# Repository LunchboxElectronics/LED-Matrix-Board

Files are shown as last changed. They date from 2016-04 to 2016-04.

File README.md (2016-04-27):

# README #

Whoray a LEGO compatible LED Matrix Board!!

### What is this repository for? ###

This repo supplies instructions and source files to create and make derivatives of the LED Matrix Board kit. This kit is an array of 49 LEDs to be incorperated into existing brick projects. The board is compatible with LEGO sets.

* This repo contains:
Eagle Files 
Arduino code to run the display and animate a smile

### How do I get set up? ###

* Code is written in Arduino
* Board file and schematic are created in Eagle

### Licensing ###
LED Matrix Board is an open source hardware product and follows the open source hardware definition: www.oshwa.org/definition The Eagle Files are licensed CC-BY-SA: Lunchbox Electronics.

### Warrenty ###
Distributed as-is; no warranty given. Not suitable for people who might eat electronics.

### Who do I talk to? ###

* Created by Jason Brownstein @ Lunchbox Electronics 9/24/15
* Contact contact@lunchboxelectronics.com

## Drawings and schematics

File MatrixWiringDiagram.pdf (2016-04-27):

# LED Matrix Board Hook-Up

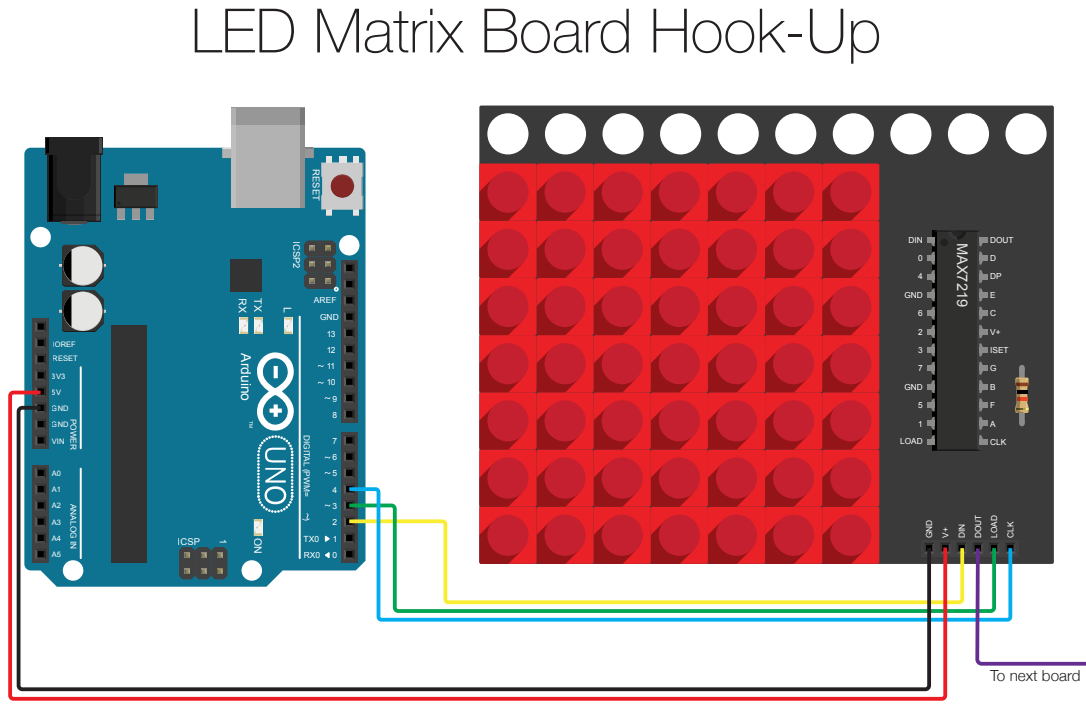
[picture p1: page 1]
ANALOG IN; AREF; GND; RESET; VIN; DIGITAL (PWM= ); Arduino TM; IOREF; ICSP; ICSP2; POWER; RX0RESET; DIN; MAX7219; DOUT; ISET; CLK; LOAD

To next board

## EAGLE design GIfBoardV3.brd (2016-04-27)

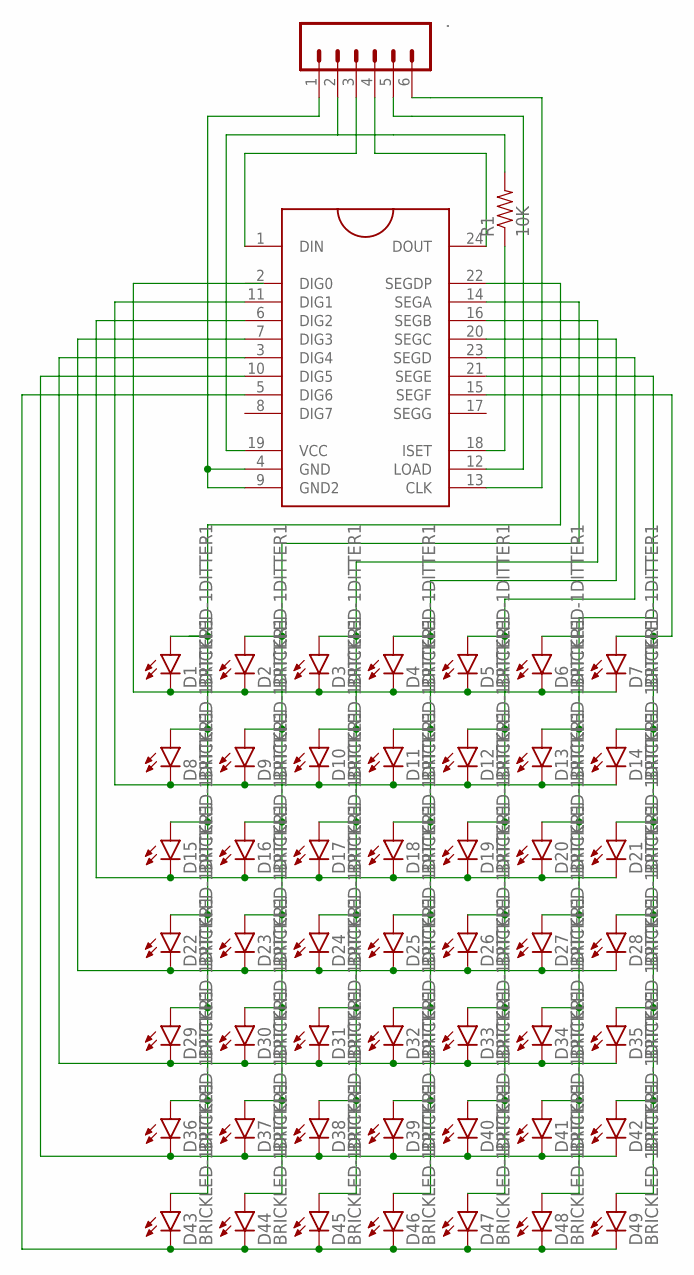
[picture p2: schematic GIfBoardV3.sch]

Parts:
.: M06NO_SILK_FEMALE_PTH; 1X06_NO_SILK
D1, D2, D3, D4, D5, D6, D7, D8, D9, D10, D11, D12, D13, D14, D15, D16, D17, D18, D19, D20, D21, D22, D23, D24, D25, D26, D27, D28, D29, D30, D31, D32, D33, D34, D35, D36, D37, D38, D39, D40, D41, D42, D43, D44, D45, D46, D47, D48, D49: BRICKLED-1DITTER1; BRICKLED-1DITTER
MAX7219: MAX7219DIP; DIL24
R1: 10K; AXIAL-0.3

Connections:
unnamed: ..4, MAX7219.24 (DOUT)
unnamed: ..5, MAX7219.12 (LOAD)
unnamed: ..3, MAX7219.1 (DIN)
unnamed: ..1, MAX7219.4 (GND), MAX7219.9 (GND2)
unnamed: D8.K (C), D9.K (C), D10.K (C), D11.K (C), D12.K (C), D13.K (C), D14.K (C), MAX7219.11 (DIG1)
unnamed: ..2, MAX7219.19 (VCC), R1.P$2 (2)
unnamed: ..6, MAX7219.13 (CLK)
unnamed: D1.A, D8.A, D15.A, D22.A, D29.A, D36.A, D43.A, MAX7219.22 (SEGDP)
unnamed: D1.K (C), D2.K (C), D3.K (C), D4.K (C), D5.K (C), D6.K (C), D7.K (C)
unnamed: D15.K (C), D16.K (C), D17.K (C), D18.K (C), D19.K (C), D20.K (C), D21.K (C), MAX7219.6 (DIG2)
unnamed: D2.A, D9.A, D16.A, D23.A, D30.A, D37.A, D44.A, MAX7219.14 (SEGA)
unnamed: D29.K (C), D30.K (C), D31.K (C), D32.K (C), D33.K (C), D34.K (C), D35.K (C), MAX7219.3 (DIG4)
unnamed: D36.K (C), D37.K (C), D38.K (C), D39.K (C), D40.K (C), D41.K (C), D42.K (C), MAX7219.10 (DIG5)
unnamed: D43.K (C), D44.K (C), D45.K (C), D46.K (C), D47.K (C), D48.K (C), D49.K (C), MAX7219.5 (DIG6)
unnamed: MAX7219.18 (ISET), R1.P$1 (1)
unnamed: D3.A, D10.A, D17.A, D24.A, D31.A, D38.A, D45.A, MAX7219.16 (SEGB)
unnamed: D5.A, D12.A, D19.A, D26.A, D33.A, D40.A, D47.A, MAX7219.23 (SEGD)
unnamed: D4.A, D11.A, D18.A, D25.A, D32.A, D39.A, D46.A, MAX7219.20 (SEGC)
unnamed: D6.A, D13.A, D20.A, D27.A, D34.A, D41.A, D48.A, MAX7219.21 (SEGE)
unnamed: D7.A, D14.A, D21.A, D28.A, D35.A, D42.A, D49.A, MAX7219.15 (SEGF)
unnamed: D22.K (C), D23.K (C), D24.K (C), D25.K (C), D26.K (C), D27.K (C), D28.K (C), MAX7219.7 (DIG3)

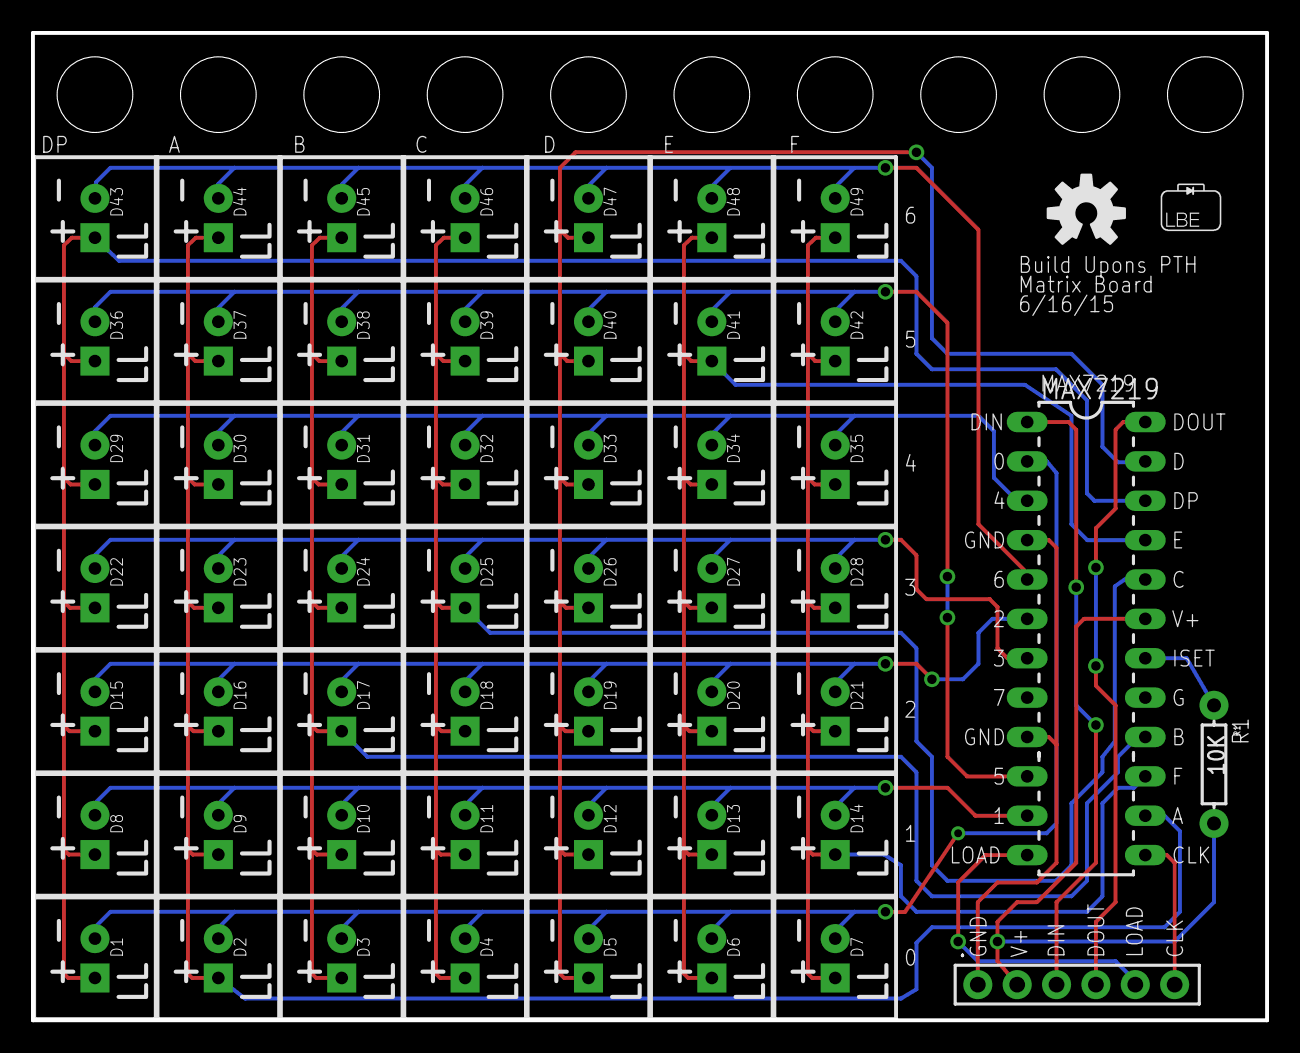
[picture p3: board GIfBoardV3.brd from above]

Board: 2 copper layers, 79.6 x 63.7 mm, 54 parts (0 on the bottom side), 21 nets.

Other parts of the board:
U$2: OSHW-LOGO-M
U$3: LUNCHBOXELECTRONICS

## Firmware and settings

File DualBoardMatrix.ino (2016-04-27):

/* code for max 7219 from maxim, 
reduced and optimised for using more than one 7219 in a row,
______________________________________

 Code History:
 --------------

The original code was written for the Wiring board by:
 * Nicholas Zambetti and Dave Mellis /Interaction Design Institute Ivrea /Dec 2004
 * http://www.potemkin.org/uploads/Wiring/MAX7219.txt

First modification by:
 * Marcus Hannerstig/  K3, malmÃ¶ hÃ¶gskola /2006
 * http://www.xlab.se | http://arduino.berlios.de

This version is by:
 * tomek ness /FH-Potsdam / Feb 2007
 * http://design.fh-potsdam.de/ 

 * @acknowledgements: eric f. 

-----------------------------------

General notes: 

-if you are only using one max7219, then use the function maxSingle to control
 the little guy ---maxSingle(register (1-8), collum (0-255))

-if you are using more than one max7219, and they all should work the same, 
then use the function maxAll ---maxAll(register (1-8), collum (0-255))

-if you are using more than one max7219 and just want to change something
at one little guy, then use the function maxOne
---maxOne(Max you want to control (1== the first one), register (1-8), 
column (0-255))

During initiation, be sure to send every part to every max7219 and then
upload it.
For example, if you have five max7219's, you have to send the scanLimit 5 times
before you load it-- otherwise not every max7219 will get the data. the
function maxInUse keeps track of this, just tell it how many max7219 you are
using.
*/

int dataIn = 2;
int load = 3;
int clock = 4;

int maxInUse = 2;    //change this variable to set how many MAX7219's you'll use

int e = 0;           // just a variable

// define max7219 registers
byte max7219_reg_noop        = 0x00;
byte max7219_reg_digit0      = 0x01;
byte max7219_reg_digit1      = 0x02;
byte max7219_reg_digit2      = 0x03;
byte max7219_reg_digit3      = 0x04;
byte max7219_reg_digit4      = 0x05;
byte max7219_reg_digit5      = 0x06;
byte max7219_reg_digit6      = 0x07;
byte max7219_reg_digit7      = 0x08;
byte max7219_reg_decodeMode  = 0x09;
byte max7219_reg_intensity   = 0x0a;
byte max7219_reg_scanLimit   = 0x0b;
byte max7219_reg_shutdown    = 0x0c;
byte max7219_reg_displayTest = 0x0f;

void putByte(byte data) {
  byte i = 8;
  byte mask;
  while(i > 0) {
    mask = 0x01 << (i - 1);      // get bitmask
    digitalWrite( clock, LOW);   // tick
    if (data & mask){            // choose bit
      digitalWrite(dataIn, HIGH);// send 1
    }else{
      digitalWrite(dataIn, LOW); // send 0
    }
    digitalWrite(clock, HIGH);   // tock
    --i;                         // move to lesser bit
  }
}

void maxSingle( byte reg, byte col) {    
//maxSingle is the "easy"  function to use for a single max7219

  digitalWrite(load, LOW);       // begin     
  putByte(reg);                  // specify register
  putByte(col);//((data & 0x01) * 256) + data >> 1); // put data   
  digitalWrite(load, LOW);       // and load da stuff
  digitalWrite(load,HIGH); 
}

void maxAll (byte reg, byte col) {    // initialize  all  MAX7219's in the system
  int c = 0;
  digitalWrite(load, LOW);  // begin     
  for ( c =1; c<= maxInUse; c++) {
  putByte(reg);  // specify register
  putByte(col);//((data & 0x01) * 256) + data >> 1); // put data
    }
  digitalWrite(load, LOW);
  digitalWrite(load,HIGH);
}

void maxOne(byte maxNr, byte reg, byte col) {    
//maxOne is for addressing different MAX7219's, 
//while having a couple of them cascaded

  int c = 0;
  digitalWrite(load, LOW);  // begin     

  for ( c = maxInUse; c > maxNr; c--) {
    putByte(0);    // means no operation
    putByte(0);    // means no operation
  }

  putByte(reg);  // specify register
  putByte(col);//((data & 0x01) * 256) + data >> 1); // put data 

  for ( c =maxNr-1; c >= 1; c--) {
    putByte(0);    // means no operation
    putByte(0);    // means no operation
  }

  digitalWrite(load, LOW); // and load da stuff
  digitalWrite(load,HIGH); 
}


void setup () {

  pinMode(dataIn, OUTPUT);
  pinMode(clock,  OUTPUT);
  pinMode(load,   OUTPUT);

  digitalWrite(13, HIGH);  

//initiation of the max 7219
  maxAll(max7219_reg_scanLimit, 0x07);      
  maxAll(max7219_reg_decodeMode, 0x00);  // using an led matrix (not digits)
  maxAll(max7219_reg_shutdown, 0x01);    // not in shutdown mode
  maxAll(max7219_reg_displayTest, 0x00); // no display test
   for (e=1; e<=8; e++) {    // empty registers, turn all LEDs off 
    maxAll(e,0);
  }
  maxAll(max7219_reg_intensity, 0x08 & 0x08);    // the first 0x0f is the value you can set
                                                  // range: 0x00 to 0x0f
}  

void loop () {

  //if you use just one MAX7219 it should look like this
  /*
    maxSingle(1,1);                       //  + - - - - - - -
   maxSingle(2,2);                       //  - + - - - - - -
   maxSingle(3,4);                       //  - - + - - - - -
   maxSingle(4,8);                       //  - - - + - - - -
   maxSingle(5,16);                      //  - - - - + - - -
   maxSingle(6,32);                      //  - - - - - + - -
   maxSingle(7,64);                      //  - - - - - - + -
   maxSingle(8,128);                      //  - - - - - - - +
  /*

 //if you use more than one MAX7219, it should look like this
  /*
  maxAll(1,1);                       //  + - - - - - - -
  maxAll(2,3);                       //  + + - - - - - -
  maxAll(3,7);                       //  + + + - - - - -
  maxAll(4,15);                      //  + + + + - - - -
  maxAll(5,31);                      //  + + + + + - - -
  maxAll(6,63);                      //  + + + + + + - -
  maxAll(7,127);                     //  + + + + + + + -
  maxAll(8,255);                     //  + + + + + + + +
  */ 


  //if you use more than one max7219 the second one should look like this
  /*
  maxOne(2,1,2);                       //  + - - - - - - -
  maxOne(2,2,4);                       //  - + - - - - - -
  maxOne(2,3,8);                       //  - - + - - - - -
  maxOne(2,4,16);                      //  - - - + - - - -
  maxOne(2,5,32);                      //  - - - - + - - -
  maxOne(2,6,64);                      //  - - - - - + - -
  maxOne(2,7,128);                     //  - - - - - - + -
  //maxOne(2,8,128);                   //  - - - - - - - +
  
  maxOne(1,1,2);                       //  + - - - - - - -
  maxOne(1,2,4);                       //  - + - - - - - -
  maxOne(1,3,8);                       //  - - + - - - - -
  maxOne(1,4,16);                      //  - - - + - - - -
  maxOne(1,5,32);                      //  - - - - + - - -
  maxOne(1,6,64);                      //  - - - - - + - -
  maxOne(1,7,128);
  */
  Heart();
  Smile();
  

}

void Heart() {
  
  maxOne(1,1,0); 
  maxOne(1,2,16);
  maxOne(1,3,56);
  maxOne(1,4,124);
  maxOne(1,5,254);
  maxOne(1,6,238);
  maxOne(1,7,68);
  maxOne(1,8,0);
  
  delay(2000);
  
  maxOne(1,1,16);
  maxOne(1,2,56);
  maxOne(1,3,124);
  maxOne(1,4,254);
  maxOne(1,5,238);
  maxOne(1,6,68);
  maxOne(1,7,0);
  maxOne(1,8,0);
}

void Smile(){
  
  maxOne(2,7,56);
  maxOne(2,6,68);
  maxOne(2,5,130);
  maxOne(2,4,0);
  maxOne(2,3,108);
  maxOne(2,2,108);
  maxOne(2,1,0);
  
  delay(2000);
  
  maxOne(2,7,0);
  maxOne(2,6,56);
  maxOne(2,5,68);
  maxOne(2,4,130);
  maxOne(2,3,0);
  maxOne(2,2,108);
  maxOne(2,1,108);

}
  

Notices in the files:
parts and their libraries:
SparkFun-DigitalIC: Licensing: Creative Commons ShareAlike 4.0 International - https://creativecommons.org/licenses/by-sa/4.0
